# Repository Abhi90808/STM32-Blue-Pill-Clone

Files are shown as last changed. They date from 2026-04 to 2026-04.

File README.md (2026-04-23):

# STM32 Blue Pill Clone

A custom recreation of the popular STM32F103C8T6 "Blue Pill" ARM Cortex-M3 development board, designed in KiCad 8 with improved layout, better decoupling, and optional USB support.

---

## Features
- STM32F103C8T6 ARM Cortex-M3 MCU @ up to 72MHz
- Onboard 8MHz crystal + 32.768kHz RTC crystal
- USB Full-Speed port (12Mbit/s)
- SWD debug/programming header
- Boot0/Boot1 jumpers
- All 37 GPIO pins broken out
- 3.3V LDO onboard
- Improved power decoupling vs original Blue Pill

## Specifications

| Parameter | Value |
|---|---|
| MCU | STM32F103C8T6 |
| Core | ARM Cortex-M3 |
| Clock Speed | Up to 72MHz |
| Operating Voltage | 3.3V |
| USB Input | 5V via Micro USB |
| Flash Memory | 64KB |
| SRAM | 20KB |
| GPIO Pins | 37 |
| ADC Channels | 10 (12-bit) |
| PCB Layers | 2 |
| Designed With | KiCad 8 |

## Project Structure

```
├── Schematic/       # KiCad schematic (.kicad_sch, PDF)
├── PCB/             # PCB layout (.kicad_pcb, .kicad_pro)
├── Gerbers/         # Fabrication files
├── BOM/             # Bill of materials (CSV)
├── 3D/              # 3D model (.step)
└── Images/          # PCB renders and schematic screenshots
```

## How It Works

The STM32F103C8T6 is clocked by an 8MHz external crystal, which the internal PLL multiplies to 72MHz. Programming is done via the SWD header using ST-Link V2. The USB port supports DFU bootloader flashing without an external programmer.

## Programming Options

| Method | Tool |
|---|---|
| SWD | ST-Link V2 + STM32CubeIDE / OpenOCD |
| USB DFU | STM32CubeProgrammer (Boot0 = 1) |
| Serial | UART1 + STM32CubeProgrammer (Boot0 = 1) |
| Arduino | Arduino IDE + STM32duino core |

## Bill of Materials (Summary)

| Component | Value | Qty |
|---|---|-----|
| MCU | STM32F103C8T6 | 1 |
| Crystal | 8MHz | 1 |
| RTC Crystal | 32.768kHz | 1 |
| LDO Regulator | AMS1117-3.3V | 1 |
| USB Connector | Micro-B | 1 |
| SWD Header | 4-pin, 2.54mm | 1 |
| Decoupling Caps | 100nF | 8 |

## Fabrication

Gerber files are in `/Gerbers`, ready for JLCPCB, PCBWay, or similar.

## License

This project is licensed under the [CERN Open Hardware Licence Version 2 - Strongly Reciprocal (CERN OHL-S v2)](https://ohwr.org/cern_ohl_s_v2.txt).

## Author

**Abhi90808** — [GitHub Profile](https://github.com/Abhi90808)

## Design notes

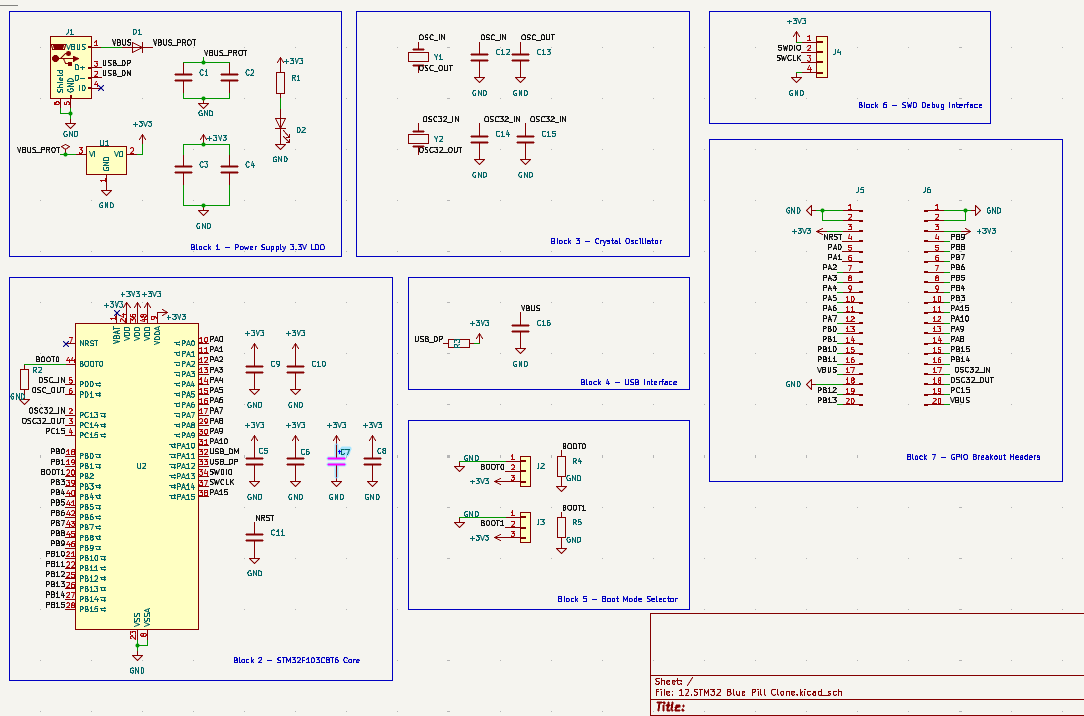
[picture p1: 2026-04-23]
Screenshot 2026-04-23 073135.png

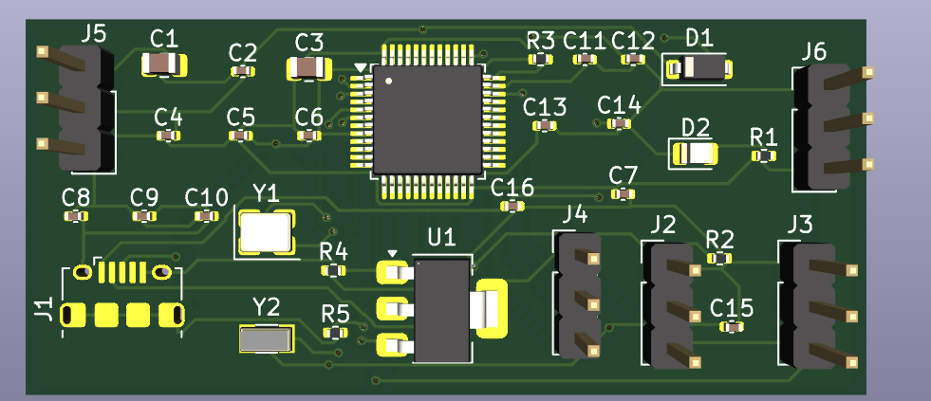
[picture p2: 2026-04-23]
Screenshot 2026-04-23 073112.png

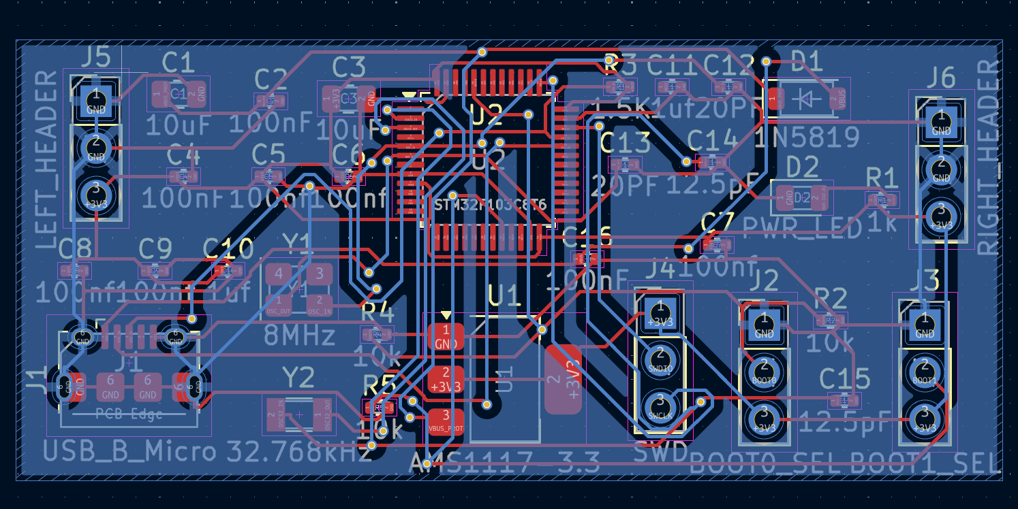
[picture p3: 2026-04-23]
Screenshot 2026-04-23 073044.png

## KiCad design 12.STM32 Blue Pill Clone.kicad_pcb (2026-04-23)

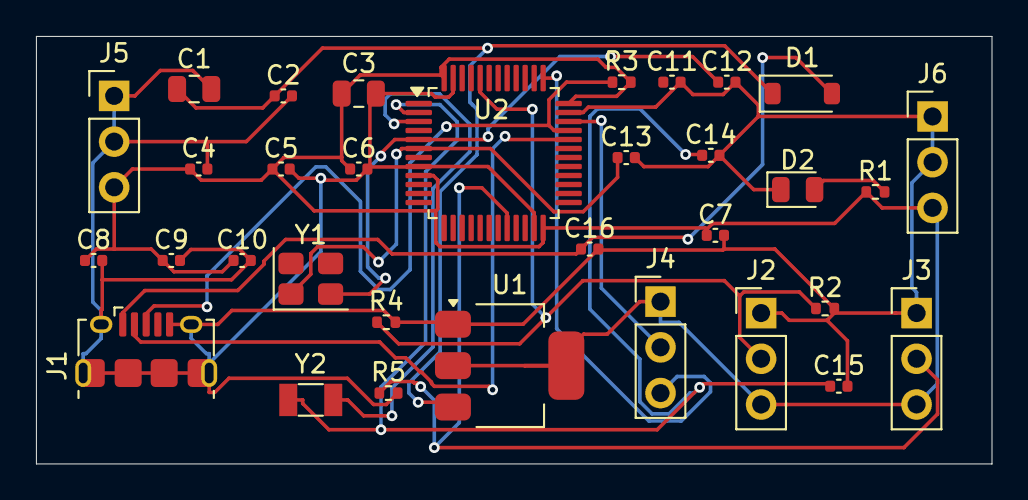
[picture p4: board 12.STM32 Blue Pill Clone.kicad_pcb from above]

Board: 2 copper layers, 53.1 x 23.7 mm, 33 parts (0 on the bottom side), 15 nets.

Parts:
C1, C3: 10uF; C_0805_2012Metric
C2, C4, C16: 100nF; C_0402_1005Metric
C5, C6, C7, C8, C9: 100nf; C_0402_1005Metric
C10, C11: 1uf; C_0402_1005Metric
C12, C13: 20PF; C_0402_1005Metric
C14, C15: 12.5pF; C_0402_1005Metric
D1: 1N5819; D_SOD-123
D2: PWR_LED; LED_0805_2012Metric
J1: USB_B_Micro; USB_Micro-B_Amphenol_10118194_Horizontal
J2: BOOT0_SEL; PinHeader_1x03_P2.54mm_Vertical
J3: BOOT1_SEL; PinHeader_1x03_P2.54mm_Vertical
J4: SWD; PinHeader_1x03_P2.54mm_Vertical
J5: LEFT_HEADER; PinHeader_1x03_P2.54mm_Vertical
J6: RIGHT_HEADER; PinHeader_1x03_P2.54mm_Vertical
R1: 1k; R_0402_1005Metric
R2, R4, R5: 10k; R_0402_1005Metric
R3: 1.5K; R_0402_1005Metric
U1: AMS1117-3.3; SOT-223-3_TabPin2
U2: STM32F103C8T6; LQFP-48_7x7mm_P0.5mm
Y1: 8MHz; Crystal_SMD_3225-4Pin_3.2x2.5mm
Y2: 32.768kHz; Crystal_SMD_3215-2Pin_3.2x1.5mm

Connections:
+3V3: C3.1, C4.1, C5.1, C6.1, C7.1, C8.1, C9.1, C10.1, J2.3, J3.3, J4.1, J5.3, J6.3, R1.1, R3.2, U1.2 (VO), U2.9 (VDDA), U2.24 (VDD), U2.36 (VDD), U2.48 (VDD)
/ OSC32_IN: C14.1, C15.1, U2.2 (PC13), Y2.2
/BOOT0: J2.2, R2.1, R4.1, U2.44 (BOOT0)
/BOOT1: J3.2, R5.1, U2.20 (PB2)
/OSC32_OUT: U2.3 (PC14), Y2.1
/OSC_IN: C12.1, U2.5 (PD0), Y1.2
/OSC_OUT: C13.1, U2.6 (PD1), Y1.1
/SWCLK: J4.3, U2.37 (PA14)
/SWDIO: J4.2, U2.34 (PA13)
/USB_DM: J1.2 (D-), U2.32 (PA11)
/USB_DP: J1.3 (D+), R3.1, U2.33 (PA12)
/VBUS: C16.1, D1.2 (A), J1.1 (VBUS)
/VBUS_PROT: C1.1, C2.1, D1.1 (K), U1.3 (VI)
GND: C1.2, C2.2, C3.2, C4.2, C5.2, C6.2, C7.2, C8.2, C9.2, C10.2, C11.2, C12.2, C13.2, C14.2, C15.2, C16.2, D2.1 (K), J1.5 (GND), J1.6 (Shield), J2.1, J3.1, J5.1, J5.2, J6.1, J6.2, R2.2, R4.2, R5.2, U1.1 (GND), U2.8 (VSSA), U2.23 (VSS), U2.35 (VSS), U2.47 (VSS)
unnamed: D2.2 (A), R1.2
